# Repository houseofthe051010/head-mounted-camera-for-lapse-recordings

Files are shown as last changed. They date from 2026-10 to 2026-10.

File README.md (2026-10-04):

# Head mounted camera for Lapse recordings

This is a cheap head-mounted camera I built using a cheap USB camera and a TPU-printed strap. It was designed by me so that I can record Lapse while working from a first-person view.

## What I would do differently next time

Definitely get a higher FOV camera; this one can barely see what I’m doing.

## Picture of the device

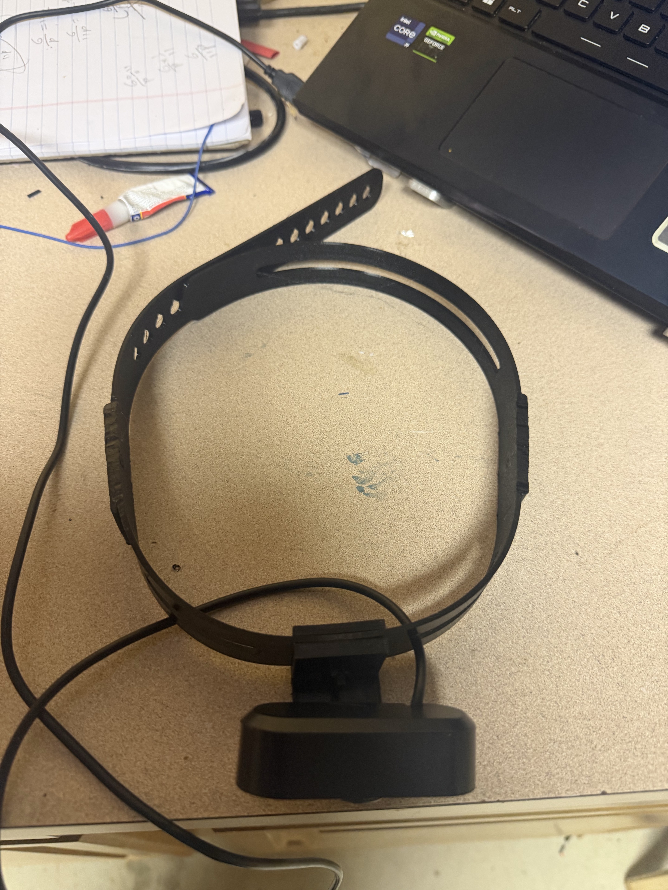
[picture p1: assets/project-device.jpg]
The head-mounted camera and TPU strap


## Fully assembled CAD

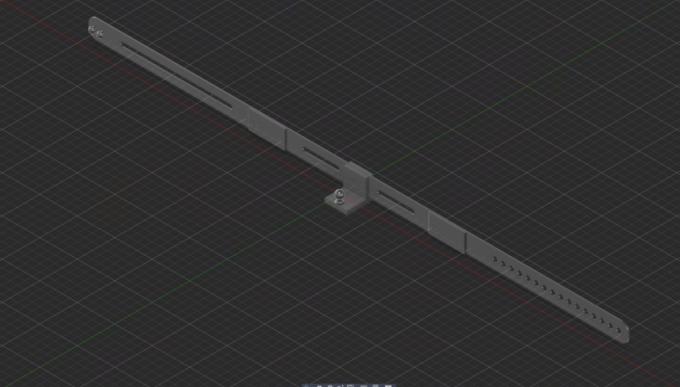
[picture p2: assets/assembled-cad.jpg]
Fully assembled CAD model of the head-mounted camera strap


## Demo video

[Watch the demo video](https://youtu.be/GmYpVjxm2xM)

## Bill of materials

| Item | Cost |
| --- | ---: |
| [USB camera](https://a.aliexpress.com/_m0Khjwj) | $4.14 |
| [TPU filament](https://www.amazon.com/dp/B0C2Z1LJGM), 56 g | $1.21 |
| [USB extender (optional, included in total)](https://a.aliexpress.com/_ms0uDrl) | $1.09 |
| [M3 button-head screw, 10 mm, and nut](https://www.amazon.com/dp/B0DFWYBJJJ) | $0.02 |
| [Super glue](https://www.amazon.com/dp/B00KPYB05A), 2 mL | $0.66 |
| **Total, including USB extender** | **$7.12** |

See the [BOM CSV](BOM.csv).

## Assembly instructions

1. First, print all the parts in the [printable STL files in the CAD folder](CAD/Individual%20STL%20files).

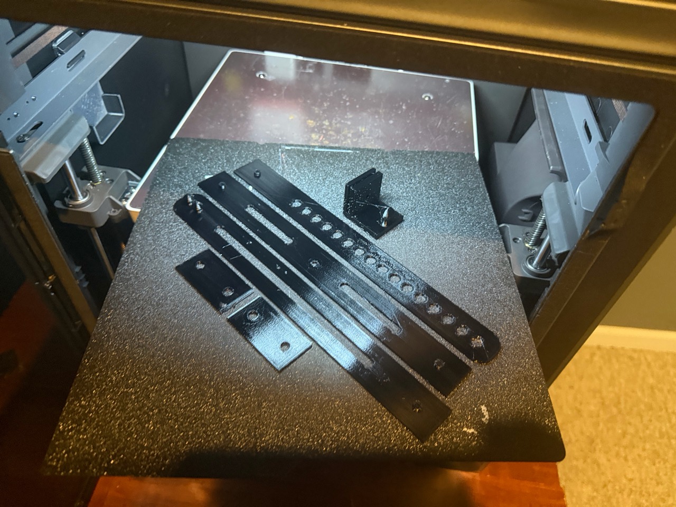
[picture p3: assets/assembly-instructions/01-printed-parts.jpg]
The printed strap and camera mount pieces
   

2. Next, get the three 240 mm strap pieces. Align them according to the CAD. Put the Adapter 240 mm piece in the center, the strap with holes on the right, and the mushroom strap on the left. The extruded circles should face each other.

3. Apply glue to the aligned pieces.

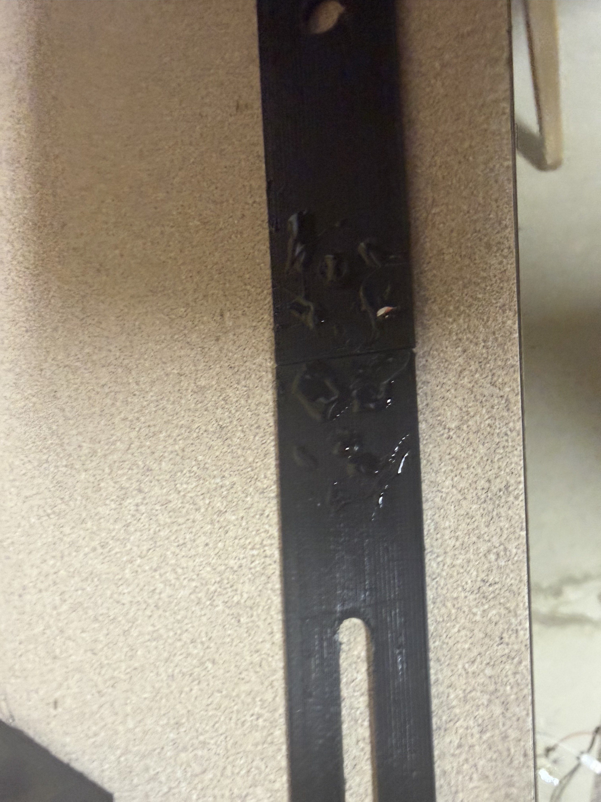
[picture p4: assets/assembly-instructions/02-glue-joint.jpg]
Glue applied to the strap joint
   

4. Put the strap joiners on, making sure they mesh with the extruded circles.

5. To further secure the attachment, use a soldering iron to melt the plastic pieces together.

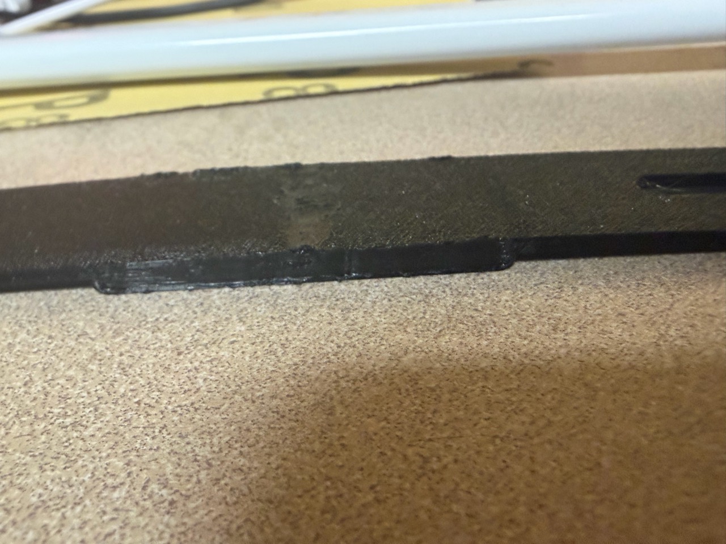
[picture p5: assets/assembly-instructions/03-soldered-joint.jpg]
The strap joint after using a soldering iron
   

6. Use an M3 button-head screw that is 10 mm long and a nut to secure the camera adapter to the strap.

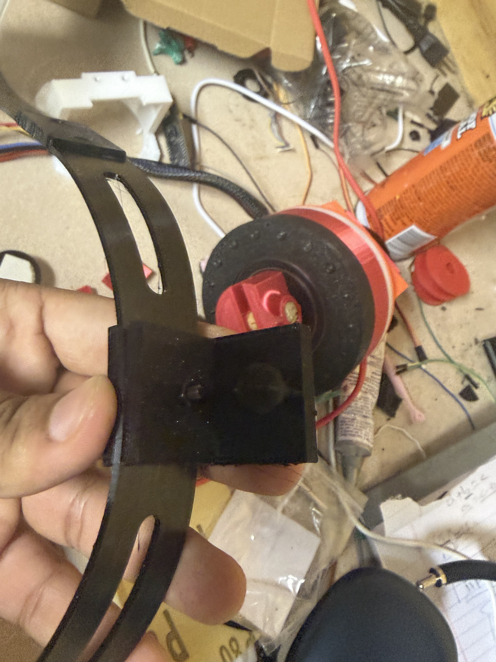
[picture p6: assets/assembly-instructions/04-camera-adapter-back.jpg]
Back of the camera adapter and strap connection
   

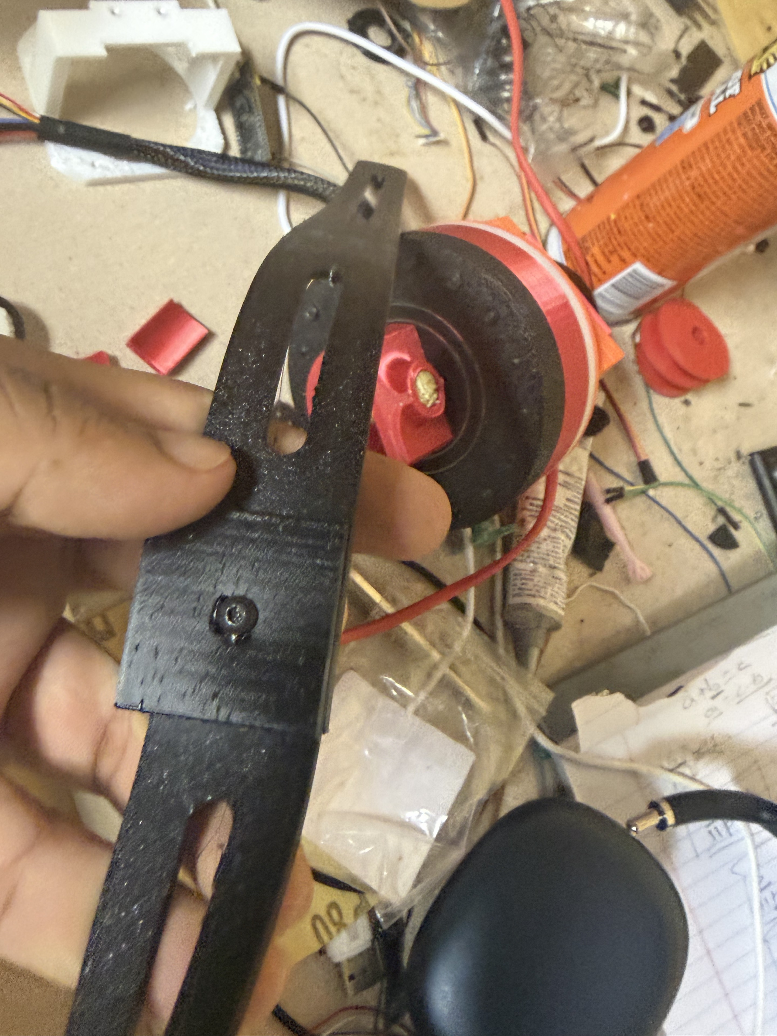
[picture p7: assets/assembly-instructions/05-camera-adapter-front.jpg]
Front of the camera adapter and strap connection
   

7. Put the camera on the ball pivot. You can attach a USB extender for more range if you have one. Connect it to your computer to record.

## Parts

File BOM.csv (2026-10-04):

Item | Quantity | Cost (USD) | Link
USB camera | 1 | 4.14 | https://a.aliexpress.com/_m0Khjwj
TPU filament | 56 g | 1.21 | https://www.amazon.com/dp/B0C2Z1LJGM
USB extender (optional; included in total) | 1 | 1.09 | https://a.aliexpress.com/_ms0uDrl
M3 button-head screw (10 mm) and nut | 1 set | 0.02 | https://www.amazon.com/dp/B0DFWYBJJJ
Super glue | 2 mL | 0.66 | https://www.amazon.com/dp/B00KPYB05A
Total (including USB extender) |  | 7.12

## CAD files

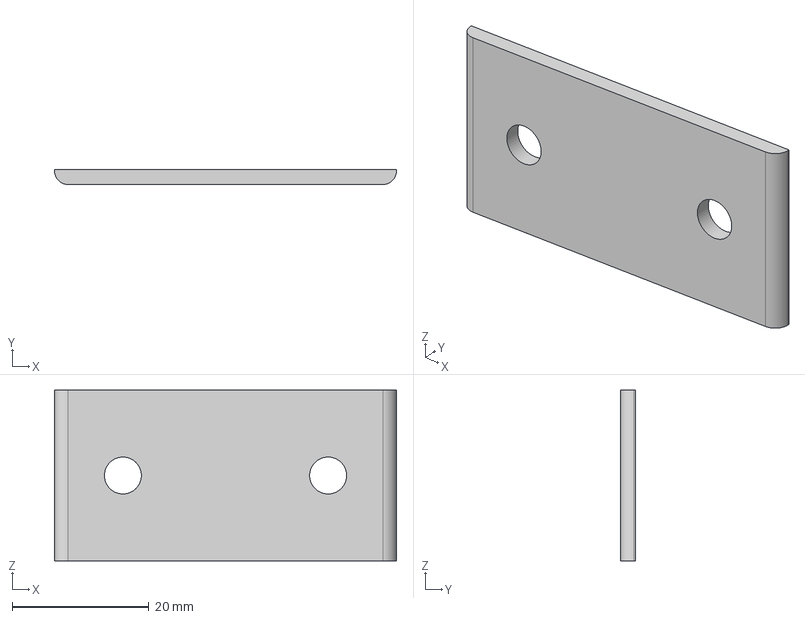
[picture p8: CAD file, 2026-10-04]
CAD/Individual STEP files/240 to 240 mm strap joiner 2.step
50.0 x 2.20 x 25.0 mm

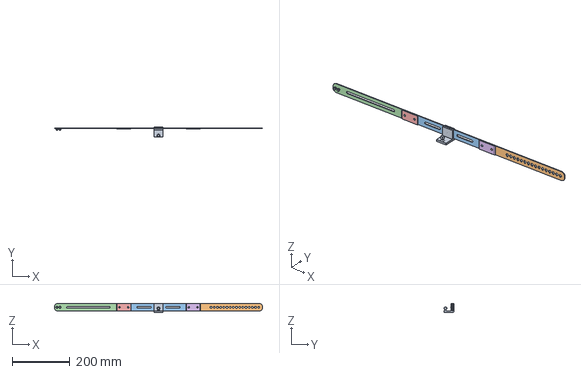
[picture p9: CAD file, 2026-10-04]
CAD/Source CAD/Strap cam.step
720.0 x 35.1 x 30.0 mm

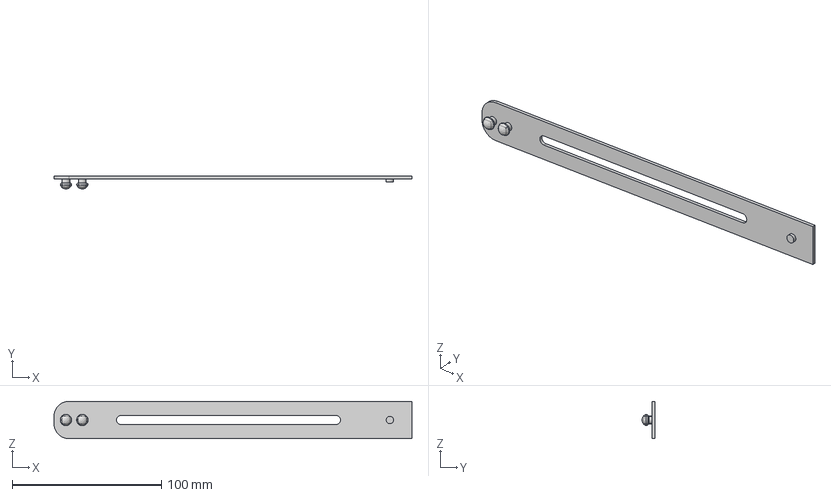
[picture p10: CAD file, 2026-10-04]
CAD/Individual STEP files/strap 240mm mushroom to hole adapter.step
239.8 x 8.80 x 25.0 mm

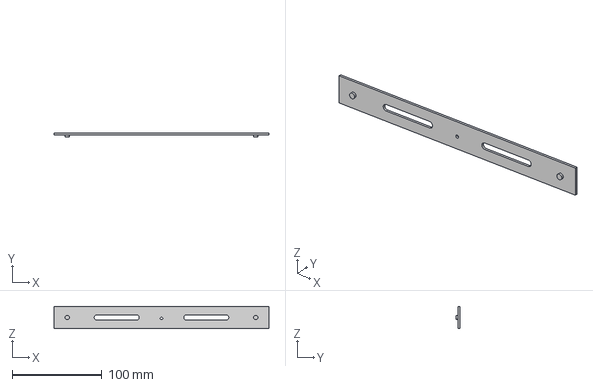
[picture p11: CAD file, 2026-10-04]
CAD/Individual STEP files/strap 240mm centerpiece adapter to mount.step
239.6 x 4.00 x 25.0 mm

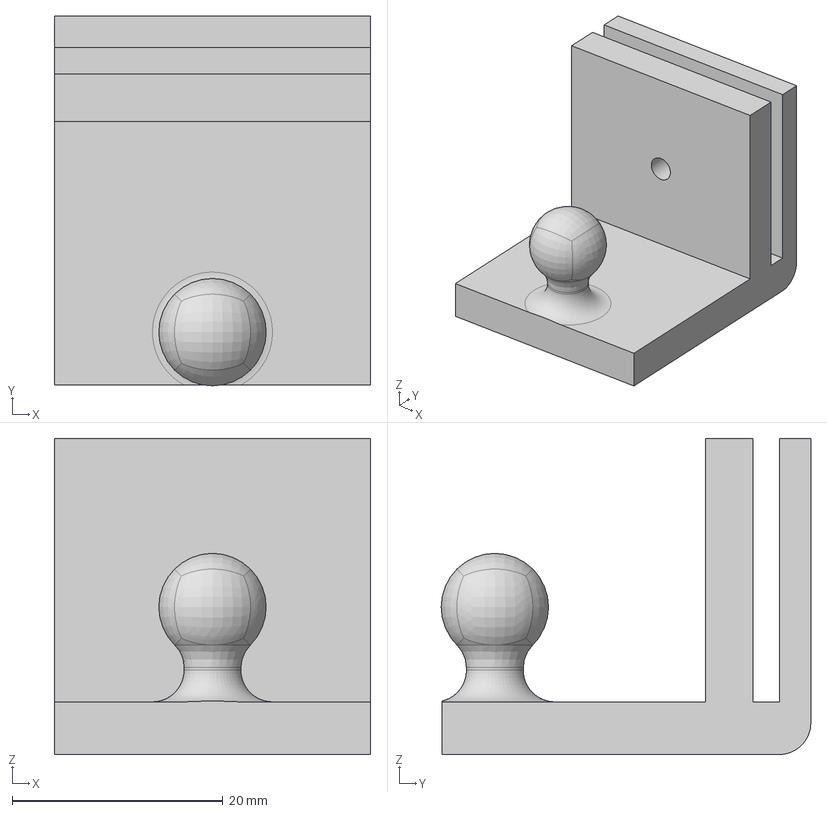
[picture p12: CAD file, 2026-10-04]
CAD/Individual STEP files/Strap to Camera Ball attachment.step
30.0 x 35.1 x 30.0 mm

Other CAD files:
CAD/Individual STEP files/240 to 240mm strap joiner 1.step
CAD/Individual STEP files/Strap 240mm attachment holes.step
CAD/Individual STL files/240 to 240 mm strap joiner 2.stl
CAD/Individual STL files/240 to 240mm strap joiner 1.stl
CAD/Individual STL files/Strap 240mm attachment holes.stl
CAD/Individual STL files/Strap to Camera Ball attachment.stl
CAD/Individual STL files/strap 240mm centerpiece adapter to mount.stl
CAD/Individual STL files/strap 240mm mushroom to hole adapter.stl
CAD/Source CAD/Strap cam.f3z

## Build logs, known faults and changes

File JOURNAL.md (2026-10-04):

---
title: "Head mounted camera for Lapse recordings"
author: "houseofthe051010"
description: "A head-mounted camera with a TPU strap for recording build time-lapse sessions."
created_at: "2026-09-26"
---

# September 26: Researching ideas

The goal of this project was to build a cheap head-mounted camera that I can use for recording lapse timelines when I am building my projects. I couldn't find a solution for this, and existing head-mounted recorders are expensive and can't record live to Lapse.

I wanted to do some research on how to make a TPU strap, so I went on MakerWorld looking for straps I can use. I needed it to adapt to my head and be adjustable for different heads. I opened Fusion and started brainstorming.

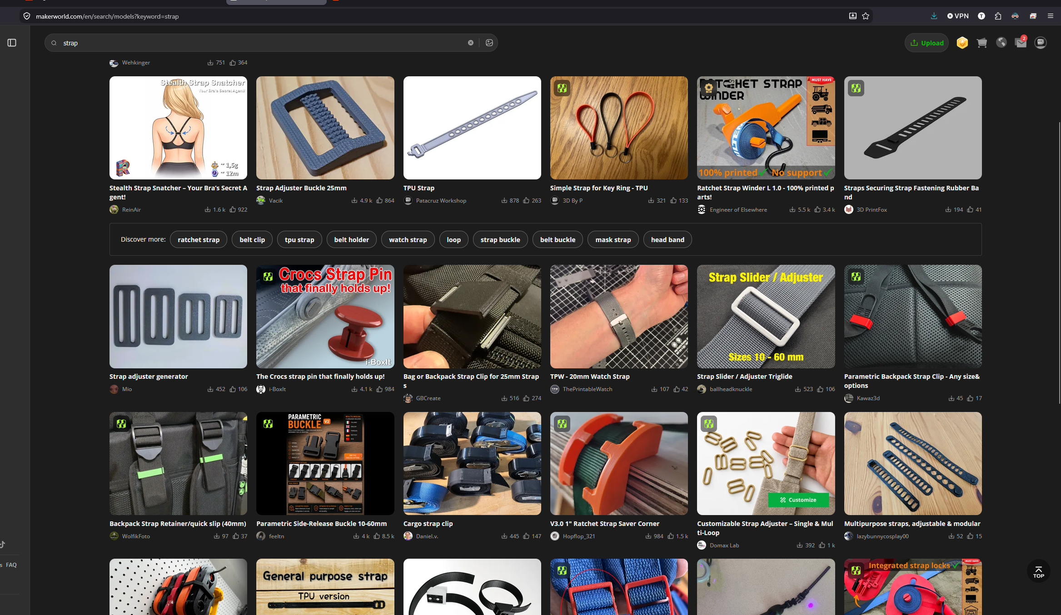
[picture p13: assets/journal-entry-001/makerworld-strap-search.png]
MakerWorld search results for straps and adjustable strap parts


I did not feel like measuring my head (I didn't have a flexible measuring tape nearby), so I just asked ChatGPT what the circumference around the forehead area of a normal adult head is.

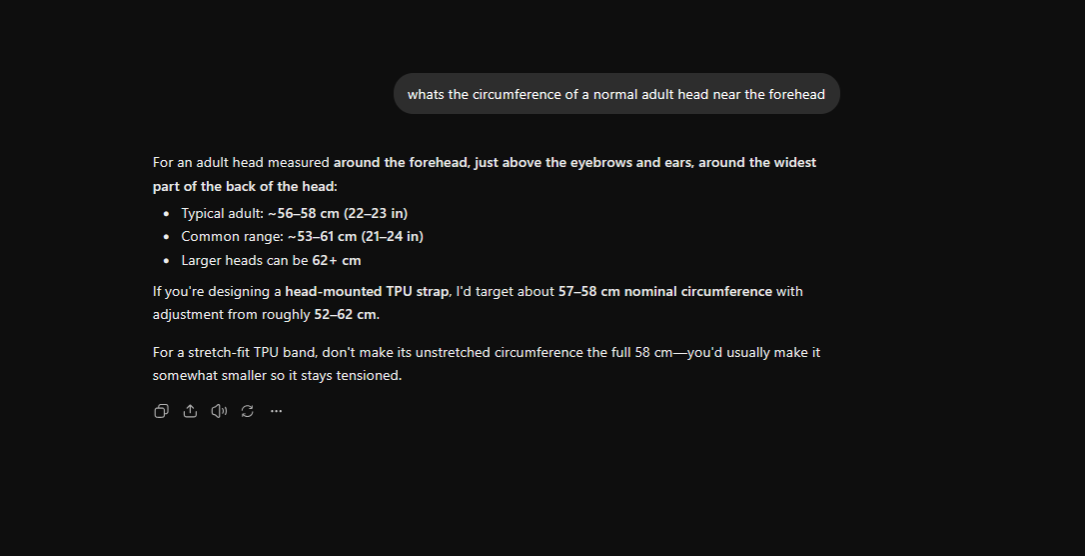
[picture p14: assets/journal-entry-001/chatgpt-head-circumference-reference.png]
ChatGPT's rough head-circumference estimate


So based on what ChatGPT said, I was going to add some headroom and make my TPU strap able to connect in those positions.

Now I am going to research what camera to use. I found it. This $4 camera is cheap on AliExpress.

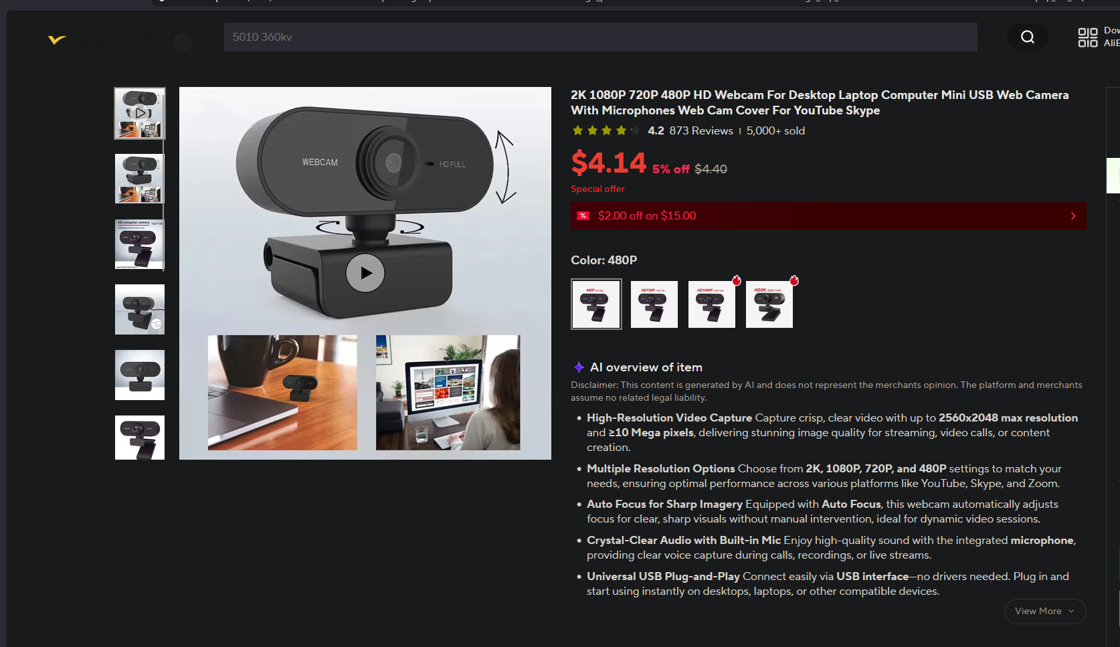
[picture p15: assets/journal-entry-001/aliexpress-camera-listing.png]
AliExpress listing for the inexpensive USB webcam


I needed to get the camera and its measurements, so I will buy it and wait for it to arrive.

Also, I will buy this USB extender so I can actually move while recording.

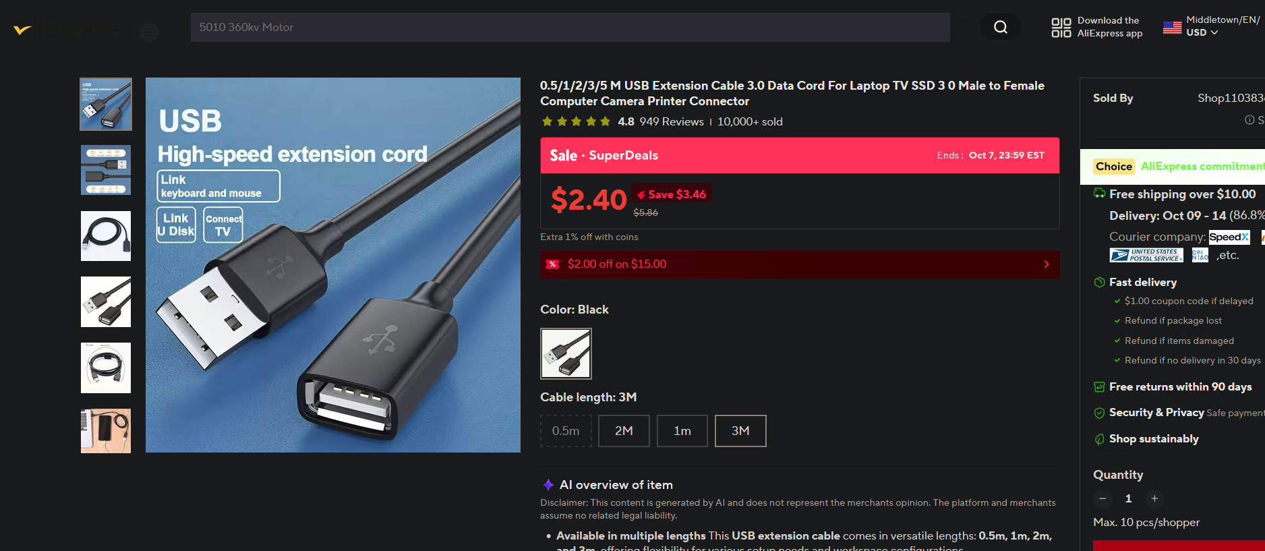
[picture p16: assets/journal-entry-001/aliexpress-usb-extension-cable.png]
AliExpress listing for the 3 m USB extension cable


**Total time spent: 15 minutes**

# October 3: Cadding the strap

I took measurements of the camera and also dried my TPU, then put it into my printer.

Here are the lapse recordings for my CAD:

- [Lapse 1](https://lapse.hackclub.com/timelapse/CsxrR57OEFcb)
- [Lapse 2](https://lapse.hackclub.com/timelapse/rOGjy3luxVwS)

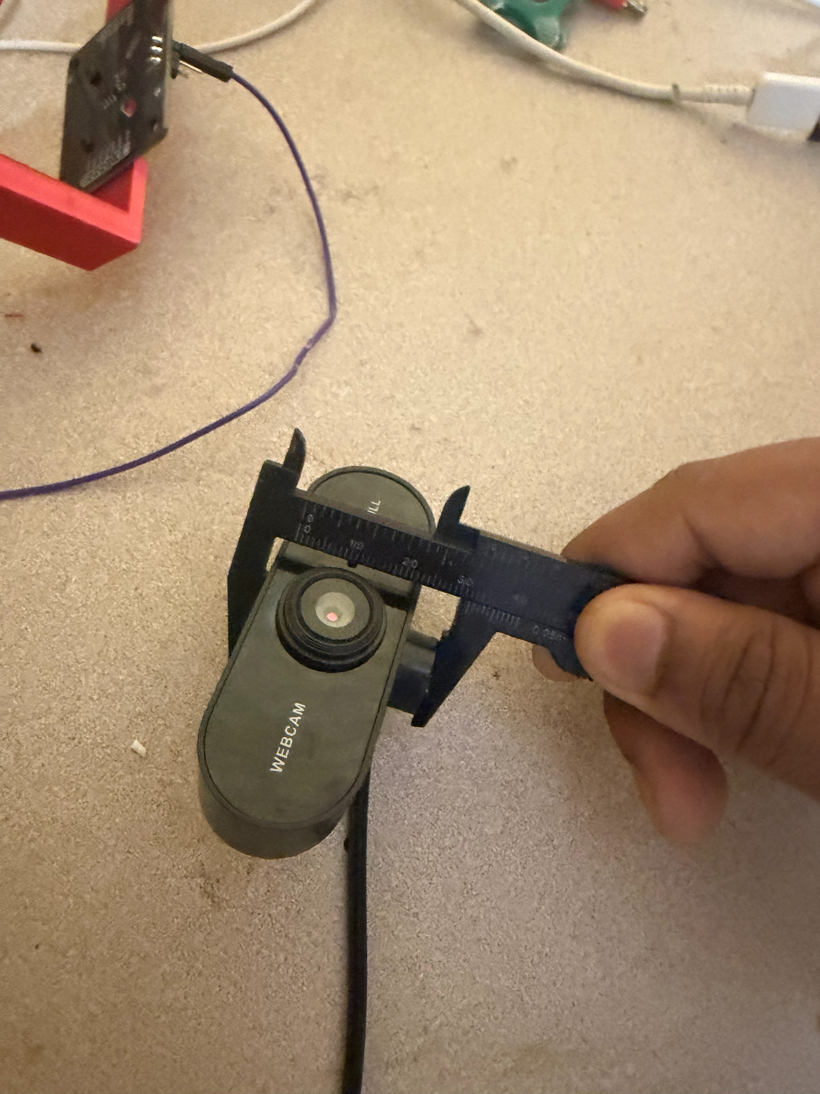
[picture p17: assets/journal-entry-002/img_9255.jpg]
Measuring the webcam with calipers


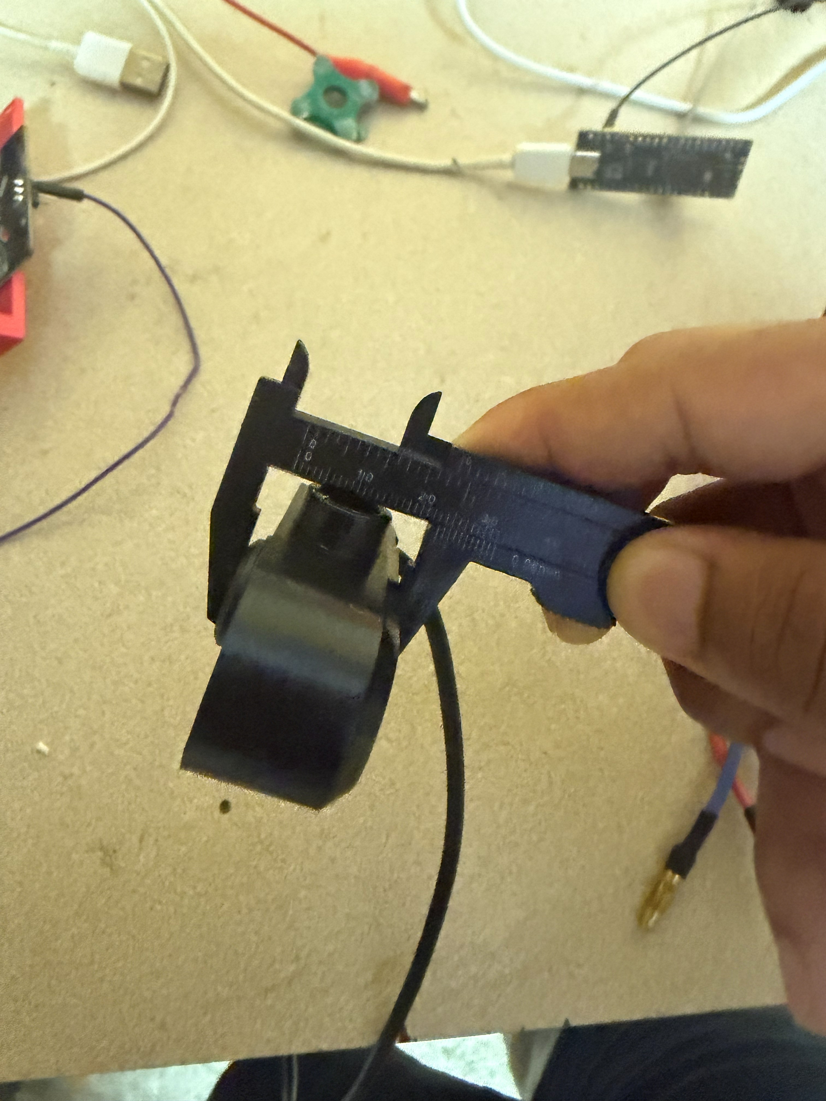
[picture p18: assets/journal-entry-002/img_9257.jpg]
Measuring another side of the webcam with calipers


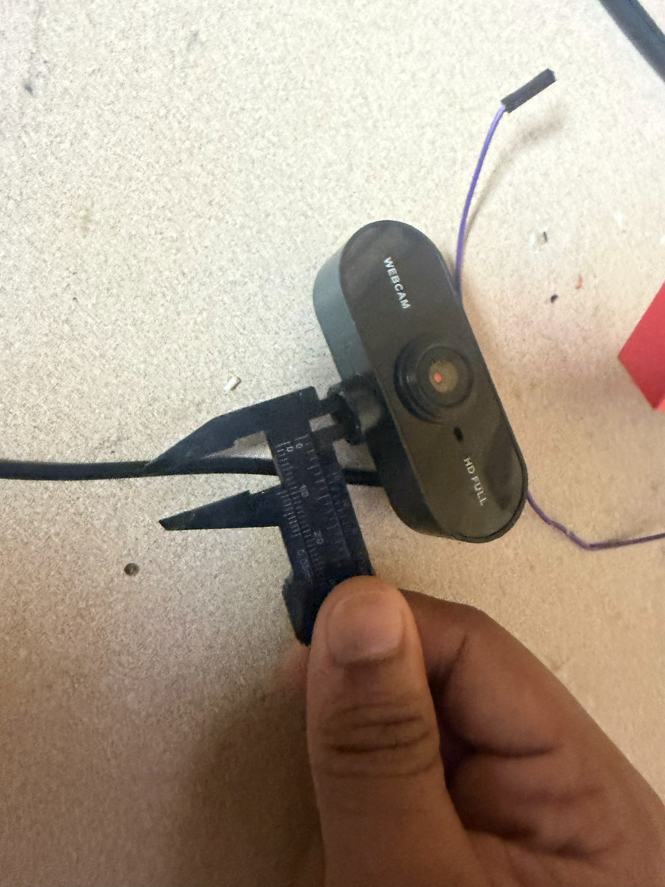
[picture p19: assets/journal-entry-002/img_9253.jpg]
Measuring the webcam body with calipers


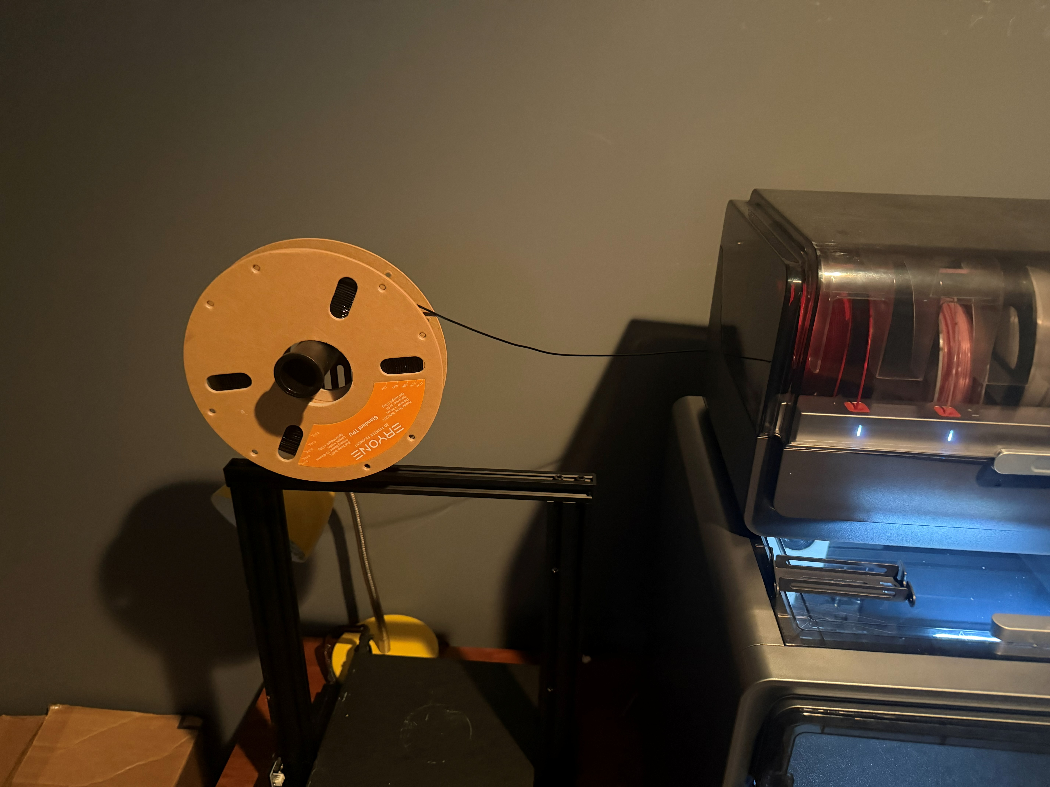
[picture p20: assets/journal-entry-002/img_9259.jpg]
Filament spool beside the 3D printer


I had CADded a strap for my camera. For a quick test, I cut some pieces and printed them to see how they fit and check the tolerances.

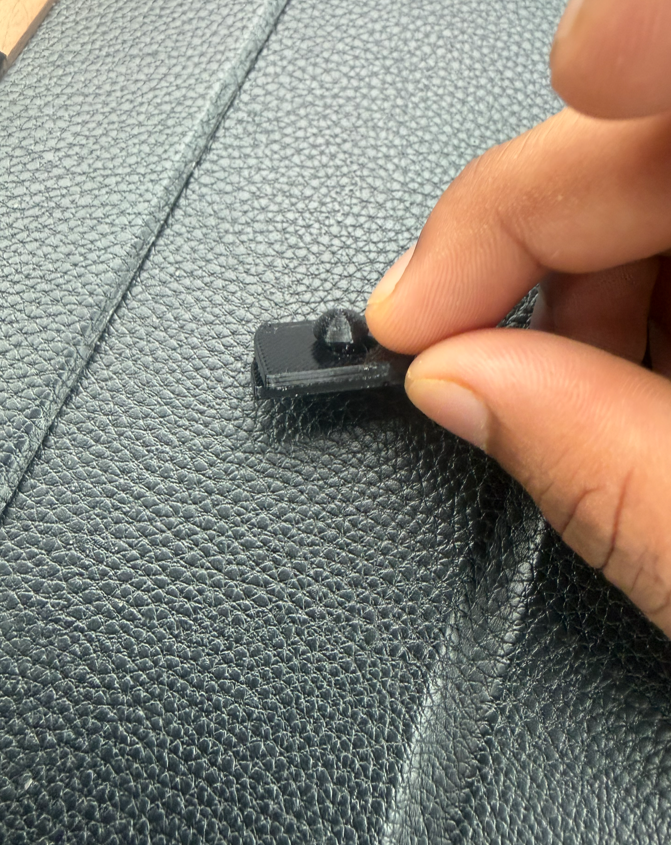
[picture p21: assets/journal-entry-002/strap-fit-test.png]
Quick test print of a camera strap attachment piece


I noticed that it was a little loose, so I went into CAD and fixed it (Lapse #2).

I will see tomorrow morning and see how it works.

**Total time spent: 2 hours**

# October 3: Building the camera and testing it

So I glued the attachment pieces together, and I actually used a soldering iron on top of the glue because I think the iron might actually be better as it joins the structure together.

So I had left it to print overnight. It was roughly 56 grams, made fully out of TPU with 100% infill.

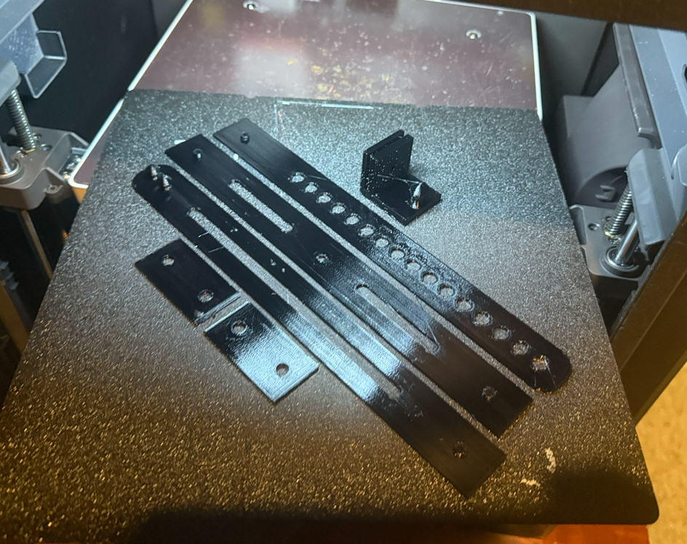
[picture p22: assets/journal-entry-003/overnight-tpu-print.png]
TPU strap pieces after the overnight print


I used super glue and a soldering iron, and it actually looked pretty good and joined together.

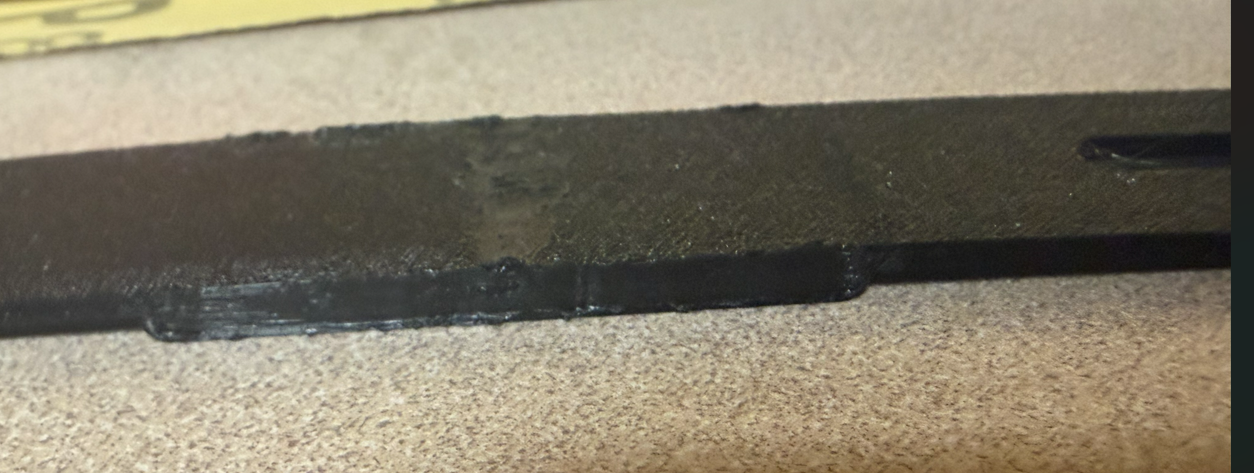
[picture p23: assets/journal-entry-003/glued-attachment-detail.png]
The glued and soldered attachment joint


These are the final results. I have also included a demo video.

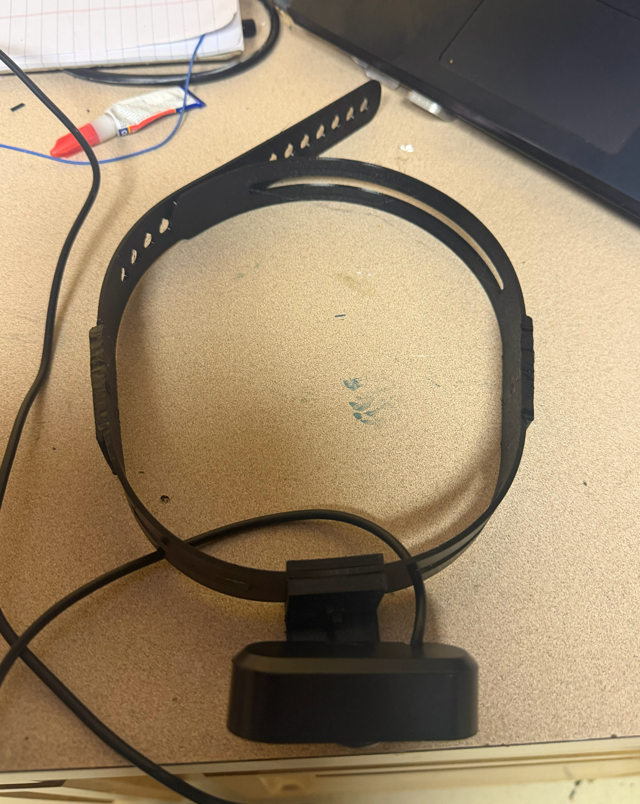
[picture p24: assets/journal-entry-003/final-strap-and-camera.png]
The final strap with the camera attached to its ball pivot


That's the final strap with the camera put on its ball pivot. The ball pivot fits nice and tight.

Here is the video of me using the final thing. One thing I noticed was that the camera FOV is so low, but it is a benefit since I can use my computer privately without the camera being able to see what I am doing, which adds privacy. Anyways, I will probably upgrade to a higher FOV, probably a fisheye camera.

Here is a demo video of me using it on my head with Lapse:

[my demo video](assets/journal-entry-003/my-demo-video.mp4)

## Extra on head pics

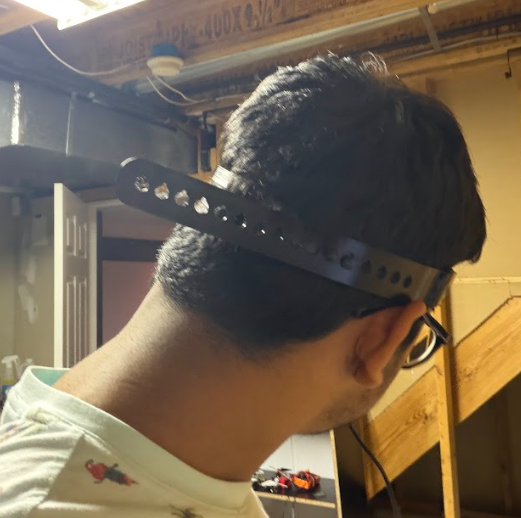
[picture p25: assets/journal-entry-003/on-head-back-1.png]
The strap from behind while I am wearing it


Another photo from behind while I am wearing the strap

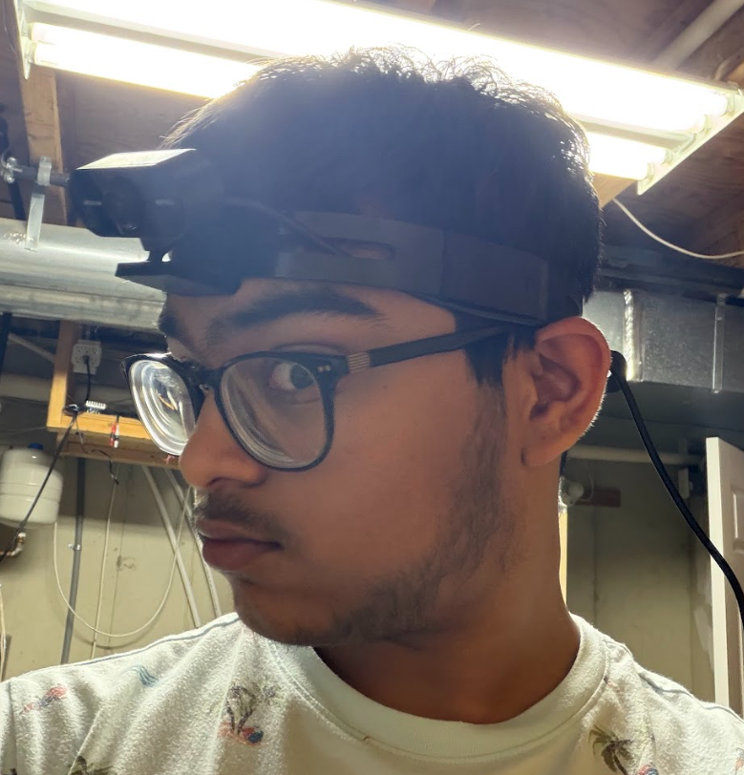
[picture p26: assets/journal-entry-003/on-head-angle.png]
The strap and camera from the side


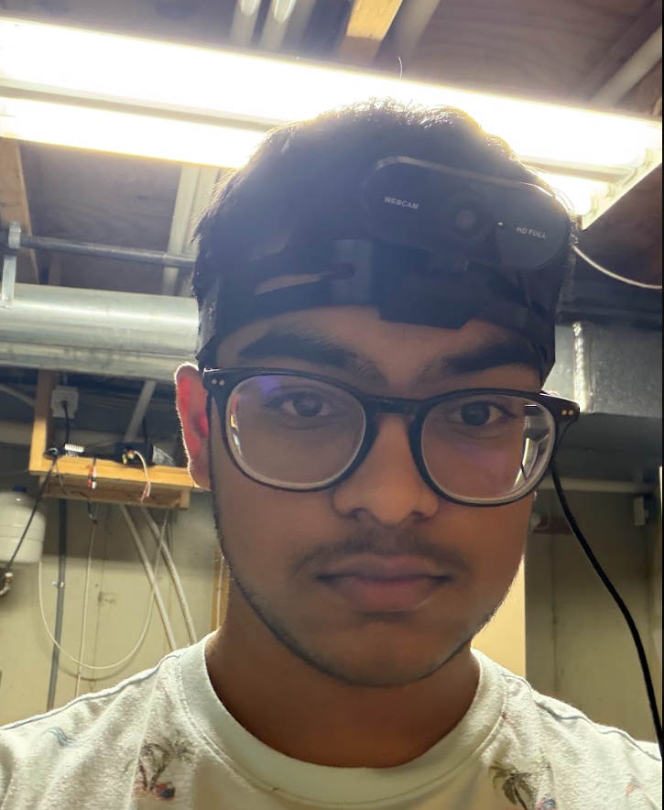
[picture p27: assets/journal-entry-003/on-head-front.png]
The strap and camera from the front


**Total time spent: 20 minutes**

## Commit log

2026-10-04 Expand README with device photo and bill of materials
2026-10-04 Simplify README bill of materials
2026-10-04 Add strap camera CAD and named part exports
    [240 to 240 mm strap joiner 2.step, 240 to 240 mm strap joiner 2.stl, 240 to 240mm strap joiner 1.step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]
2026-10-04 Add photo assembly instructions to README
2026-10-04 Fix spacing before assembly instructions
2026-10-04 Add BOM CSV and README demo assets
    [BOM.csv]
2026-10-04 Add hardware and glue costs to BOM
    [BOM.csv]
